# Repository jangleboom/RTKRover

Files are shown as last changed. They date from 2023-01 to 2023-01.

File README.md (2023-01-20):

# RTKRover
## Headtracker + Real Time Kinematics (RTK rover)

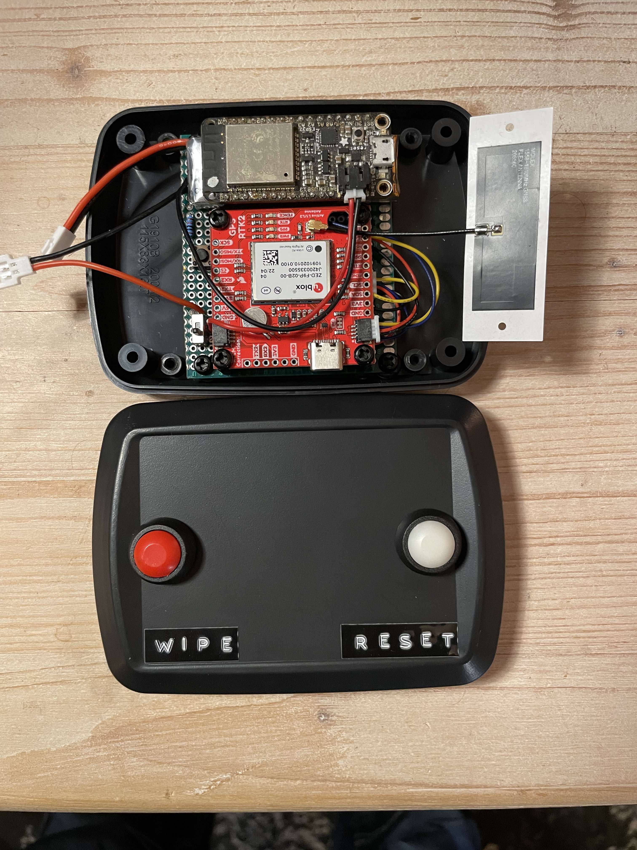
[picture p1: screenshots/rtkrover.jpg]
 

Hardware used:   
* Adafruit Feather ESP32 Huzzah 
* SparkFun GPS-RTK-SMA Breakout - ZED-F9P (Qwiic)
* SparkFun BNO080 Breakout
* ublox [ANN-MB1](https://www.u-blox.com/en/product/ann-mb-series?legacy=Current) antenna (the small one the picture is not used here at the moment)
* LiPo battery
* Push button(s)
* Resistor 10 k
* Switch

Infrastructure:
* WiFi (e. g. a personal hotspot)
* free line of sight between antenna (horizontal placed) an sky

### Dependencies
* [ESPAsyncWebServer](https://github.com/me-no-dev/ESPAsyncWebServer)
* [RTKRoverManager](https://github.com/jangleboom/RTKRoverManager)

### Circuit diagram
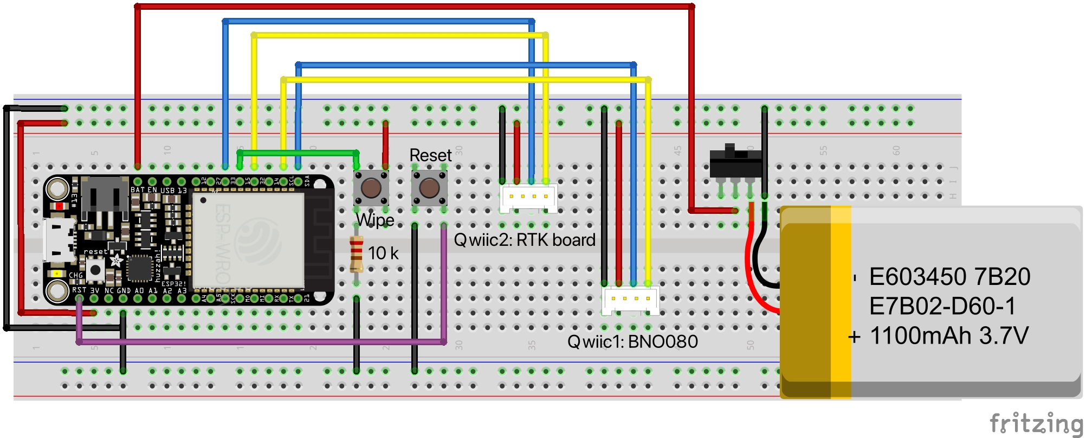
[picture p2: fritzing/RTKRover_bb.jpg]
plot


### Configuration

BNO080:

In main.cpp line 763 (or near) you can choose the way of sensor fusion in the BNO080.

````
  // Activate IMU functionalities
  // bno080.enableRotationVector(BNO080_ROT_VECT_UPDATE_RATE_MS);  
  // bno080.enableGameRotationVector(BNO080_ROT_VECT_UPDATE_RATE_MS);  
  bno080.enableARVRStabilizedRotationVector(BNO080_ROT_VECT_UPDATE_RATE_MS);

`````

more information in the [datasheet](https://www.ceva-dsp.com/wp-content/uploads/2019/10/BNO080_085-Datasheet.pdf)

ZED-F9P:

If you are NOT using the web form of the RTKBaseManager, then to connect to a caster you will need to fill out the CasterSecrets.h that lives in your src folder with your own credentials (and replace the vars with the k prefixed values e. g: ```mountPoint``` to ```kMountPoint``` in the main.cpp).

````
#ifndef CASTER_SECRETS_H
#define CASTER_SECRETS_H
// A place for your caster credentials

// RTK2Go http://www.rtk2go.com:2101/SNIP::STATUS#uptime

const char kCasterHost[] = "rtk2go.com"; 
const char kCasterPort[] = "2101";
const char kMountPoint[] = "YOUR_MOUNT_POINT";
const char kCasterUser[] = "YOUR_USER_EMAIL";           // User must provide their own email address to use RTK2Go
const char kCasterUserPw[] = "";                        // Not neccecary, more info: rtk2go.com

// Device name 
const char kDeviceName[] = "rover123";                  // E. g. 
// Wifi access
const char kWifiSsid[] = "YOUR_SSID_WITHOUT_SPACES";    // Wifi to connect the rover with
const char kWifiPw[] = "YOUR_WIFI_PASSWORD";

#endif /*** CASTER_SECRETS_H ***/

````

The mklittlefs file in the root dir you have to [get](https://github.com/earlephilhower/mklittlefs/releases) depending on your OS.
If you have the Arduino IDE installed, you can borrow it from there too. On macOS you can find it here: `~/Library/Arduino15/packages/esp32/tools/mklittlefs/3.0.0-gnu12-dc7f933/mklittlefs`.  Help for setup the file system you can find [here](https://randomnerdtutorials.com/esp8266-nodemcu-vs-code-platformio-littlefs/). This project was created on macOS (silicon).

[Support RTK2GO](http://new.rtk2go.com/donations-and-support/)

### ESP32 board LED error codes:

* 0.1 s BLE: not connected
* 0.5 s RTK: setupGNSS() failed (I2C setup)
* 1.0 s	RTK: setupGNSS() failed (I2C communication)
* 2.0 s RTK: credentialsExists false
* 1.0 s : 0.1 s WiFi: connection to AP lost

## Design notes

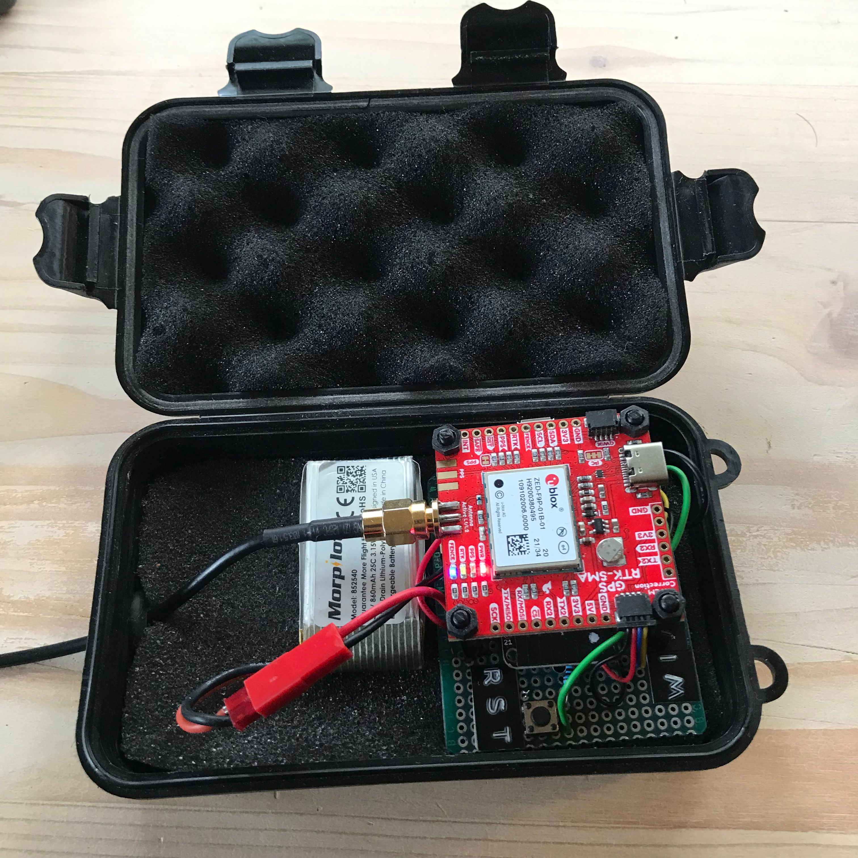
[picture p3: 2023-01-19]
screenshots/rtkrover.jpeg

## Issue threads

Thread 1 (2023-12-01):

Is the bno080 optional?

rcdemuth, 2023-12-01:
So, I'm trying to put together a rover.  I don't have one of the bno080 boards, and was wondering what it's role was.

jangleboom, 2023-12-12:
Hello rcdemuth, no – it is optional. However, if you don't want to use orientation tracking, you should comment out all of the associated BNO080 code. The device was built for an audio art project in acoustic virtual reality. In order to reproduce the sound dynamically depending on position and viewing direction, we needed both the BNO080 data and the GPS data. To use just the rover you don't need a BNO080.

Closed 2024-01-02.

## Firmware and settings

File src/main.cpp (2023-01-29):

/*******************************************************************************
 * @file main.cpp
 * @authors Markus Hädrich
 * <br>
 * @brief This is part of a distributed software, here: head tracker and GNSS 
 *        positioning using Sparkfun Real Time Kinematics
 * <br>
 * @todo  - Task to check / reconnect WiFi (independent of head tracking)
 *        - Calibration button (?)
 *        - Test: BNO080 found/connected
 *        - Test: BLE 
 *        - Status led for WiFi/BLE? on the device box or monitoring in app only?
 *        - Buzzer peep tone if lipo runs out of energy or show an blinky icon/notification in App
 *        
 * @note How to handle WiFi: 
 *        - Push the wipeButton, this will delete old entries in LittleFS files
 *        - Join the AP thats appearing 
 *            -# SSID: RTK-Rover now, later with more devices e. g. "RTKRover_" + ChipID 
 *            -# PW: e. g. "12345678"
 *        - Open address 192.168.4.1 in your browser and set credentials you are 
 *          using for you personal access point on your smartphone
 *        - If the process is done, the LED turns off and the device reboots
 *        - If there are no Wifi credentials stored in the LittleFS, the device 
 *          will jump in AP mode on startup
 * 
 *       How to measure battery:
 *        - First:  Since the ADC2 module is also used by the Wi-Fi, only one of 
 *                  them could get the preemption when using together, which means 
 *                  the adc2_get_raw() may get blocked until Wi-Fi stops, and 
 *                  vice versa. (https://docs.espressif.com/projects/esp-idf/en/latest/esp32/api-reference/peripherals/adc.html)
 *        - Second: Easiest way, use a fuel gauge breakout board e. g. Adafruit_LC709203F
 *                  Complicated way, implement an alternating usage of WiFi and ADC2
 * 
 * @version 0.43
 ******************************************************************************/


#include <Arduino.h>
#include <Wire.h> // BNO080 and uBlox GNSS
#include <BLEDevice.h>
#include <BLE2902.h>
#include <SparkFun_u-blox_GNSS_Arduino_Library.h>
#include <SparkFun_BNO080_Arduino_Library.h>
#include <utility/imumaths.h>
#include <sdkconfig.h>
#include <RTKRoverConfig.h>
#include <CasterSecrets.h>
#include <RTKRoverManager.h>
#include <TestsRTKRover.h>

using namespace RTKRoverManager;

/*
=================================================================================
                                Buttons
=================================================================================
*/
#include "Button2.h"

// Button to press to wipe out stored WiFi credentials
Button2 wipeButton = Button2(WIPE_BUTTON_PIN, INPUT, false, false);

void buttonHandler(Button2 &btn);

/*
=================================================================================
                                Battery
=================================================================================
*/
// Messure half the battery voltage
#define BAT_PIN                    A13
/**
 * @brief Get the Battery Volts 
 * 
 * @return float Battery voltage
 */
float getBatteryVolts(void);

/*
=================================================================================
                                WiFi
=================================================================================
*/
AsyncWebServer server(80);
String scannedSSIDs[MAX_SSIDS];

/*
=================================================================================
                                Bluetooth LE
=================================================================================
*/
float bleConnected = false; // TODO: deglobalize this

class MyCharacteristicCallbacks: public BLECharacteristicCallbacks 
{
    void onWrite(BLECharacteristic *pHeadtrackerCharacteristic) 
    {   
        std::string value = pHeadtrackerCharacteristic->getValue(); // Here I get the commands from the App (client)

        if (value.length() > 0) 
        {
            DBG.println(F("*********"));
            DBG.print(F("New value: "));
            for (int i = 0; i < value.length(); i++)
                DBG.print(value[i]);

            DBG.println();
            DBG.println(F("*********"));
        }
     }

     void onConnect(BLEServer* pServer) 
     {
        bleConnected = true;
        DBG.print(F("bleConnected: "));
        DBG.println(bleConnected);
     };

    void onDisconnect(BLEServer* pServer) 
    {
        bleConnected = false;
        DBG.print(("bleConnected: "));
        DBG.println(bleConnected);
    }
};

class MyServerCallbacks: public BLEServerCallbacks 
{
    void onConnect(BLEServer* pServer) 
    {
        bleConnected = true;
        BLEDevice::stopAdvertising();
    };

    void onDisconnect(BLEServer* pServer) 
    {
        bleConnected = false;
        BLEDevice::startAdvertising();
    }
};

BLECharacteristic *pHeadtrackerCharacteristic;
BLECharacteristic *pRealtimeKinematicsCharacteristic;
BLECharacteristic *pRTKAccuracyCharacteristic;

void setupBLE(void);
/*
=================================================================================
                                BNO080
=================================================================================
*/
BNO080 bno080;
void setupBNO080(void);

/*
=================================================================================
                                GNSS
=================================================================================
*/
long lastTime = 0; //Simple local timer. Limits amount if I2C traffic to Ublox module.
bool beginPositioning = false;  // Wait with positioning for first correction data from caster

// The ESP32 core has a built in base64 library but not every platform does
// We'll use an external lib if necessary.
#if defined(ARDUINO_ARCH_ESP32)
#include "base64.h" //Built-in ESP32 library
#else
#include <Base64.h> //nfriendly library from https://github.com/adamvr/arduino-base64, will work with any platform
#endif


SFE_UBLOX_GNSS myGNSS;

/**
 * @brief Setup the ZED-F9D to a rover
 * 
 * @return true If succeeded
 * @return false If failed
 */
bool setupGNSS(void);

/**
 * @brief Start the
 * 
 */
void beginClient(void);

/**
 * @brief Get the Position
 * 
 */
void updatePosition(void);

/*
=================================================================================
                                FreeRTOS
=================================================================================
*/
typedef struct Coord
{
  int32_t lat;
  int8_t  latHp;
  int32_t lon;
  int8_t  lonHp;
} coord_t;

const uint8_t QUEUE_SIZE = 2;
xQueueHandle xQueueAccuracy, xQueueCoord;
static xSemaphoreHandle mutexSem;

/**
 * @brief Task to get the correction data from the caster server
 *        using WiFi
 * 
 * @param pvParameters Void pointer, no parameter used here
 */
void task_rtk_get_corrrection_data(void *pvParameters);

/**
 * @brief Task to get location data
 * 
 * @param pvParameters 
 */

void task_rtk_get_rover_position(void *pvParameters);
/**
 * @brief Task for sending the corrected location data to the
 *        iPhone using BLE
 * 
 * @param pvParameters Void pointer, no parameter used here
 */
void task_send_rtk_position_via_ble(void *pvParameters);

/**
 * @brief Task for sending the BNO080 position data to the
 *        iPhone using BLE
 * 
 * @param pvParameters Void pointer, no parameter used here
 */
void task_bno_orientation_via_ble(void *pvParameters);

/**
 * @brief Create the queues with the right size
 * 
 */
void xQueueSetup(void);

/**
 * @brief Function that blinks one time
 * 
 * @param blinkTime       Blink time in ms
 * @param doNotBlock  Kind of delay between blinking
 */
void blinkOneTime(int blinkTime, bool doNotBlock);

/**
 * @brief Deletes WiFi station SSID and PW from LittleFS
 * 
 */
void wipeWiFiCredentials(void);

void setup() 
{
  // Board LED used for error codes (written in README.md)
  pinMode(LED_BUILTIN, OUTPUT);
  digitalWrite(LED_BUILTIN, LOW);

  #ifdef DEBUGGING
  Serial.begin(BAUD);
  while (!Serial) {};
  #endif

 //===============================================================================
  // Initialize LittleFS
  // Use board_build.partitions in platformio.ini
  if (!setupLittleFS()) 
  {
    formatLittleFS();
    if (!setupLittleFS()) while (true) {};
  }

  // The following function clear the file system and that will cause a setup as AP to enter new data

  // Uncomment if you want to format (e. g after changing partition sizes)
  // (And dont forget to comment this again after one run ;)
  //formatLittleFS();

  // wipeWiFiCredentials();  // Use this for deleting WiFi data only
  // wipeLittleFSFiles();  // Use this for deleting all data
#ifdef DEBUGGING
  listFiles();
  delay(3000);
#endif

  //===============================================================================
  // Wifi setup AP or STATION, depending on data in LittleFS
  setupWiFi(&server);
  delay(1000);

  while (WiFi.getMode() == WIFI_AP) 
  {
    DBG.println(F("Enter Wifi credentials on webform:"));
    DBG.print(F("Connect your computer to SSID: "));
    DBG.println(WiFi.getHostname());
    DBG.print(F("Go with your Browser to IP: "));
    DBG.println(WiFi.softAPIP());
    blinkOneTime(1000, false);
    blinkOneTime(100, false);
  }
  if (WiFi.getMode() == WIFI_STA) 
  {
    while (! WiFi.isConnected())
    {
      DBG.println(F("setup(): Try reconnect to WiFi station"));
      WiFi.reconnect();
      DBG.printf("WiFi state: %s", WiFi.isConnected() ? "connected" : "disconnected");
      blinkOneTime(1000, false);
      blinkOneTime(100, false);
    }
  }
//===============================================================================
  
  setupBLE();
  
  DBG.print(F("Device type: ")); DBG.println(DEVICE_TYPE);
  DBG.print(F("Battery: "));
  DBG.print(getBatteryVolts());  
  DBG.println(" V");

  wipeButton.setPressedHandler(buttonHandler); // Pull down method is done in wipeButton init

  // FreeRTOS
  mutexSem = xSemaphoreCreateMutex();
  xQueueSetup();
/*  
  Stack sizes of the tasks. You have to measure the used size in the task (set a high value for first run) and 
  after that you can reduce the stack size to an fitting smaller value. This have to repeated if 
  the task code is changed. There are no rules, just measure and adjust (thats why its a magic number).
  For measurement you need to uncomment the uxHighWaterMark related code in the task (setup and loop).
  After measurement comment out it again.
*/
  int stack_size_task_rtk_get_corrrection_data = 1024 * 7;          // Last measurement: 
  int stack_size_task_rtk_get_rover_position = 1024 * 7;      // Last measurement: 5844 
  int stack_size_task_bno_orientation_via_ble = 1024 * 11;  // Last measurement:
  int stack_size_task_send_rtk_position_via_ble = 1024 * 10;     // Last measurement: 9480
  
  xTaskCreatePinnedToCore( &task_rtk_get_corrrection_data, "task_rtk_get_corrrection_data", stack_size_task_rtk_get_corrrection_data, NULL, TASK_RTK_GET_CORR_DATA_PRIORITY, NULL, RUNNING_CORE_0);
  xTaskCreatePinnedToCore( &task_rtk_get_rover_position, "task_rtk_get_rover_position", stack_size_task_rtk_get_rover_position, NULL, TASK_RTK_GET_POSITION_PRIORITY, NULL, RUNNING_CORE_0);
  xTaskCreatePinnedToCore( &task_bno_orientation_via_ble, "task_bno_orientation_via_ble", stack_size_task_bno_orientation_via_ble, NULL, TASK_BNO080_VIA_BLE_PRIORITY, NULL, RUNNING_CORE_1);
  xTaskCreatePinnedToCore( &task_send_rtk_position_via_ble, "task_send_rtk_position_via_ble", stack_size_task_send_rtk_position_via_ble, NULL, TASK_RTK_POSITION_VIA_BLE_PRIORITY, NULL, RUNNING_CORE_1);
  
  String thisBoard = ARDUINO_BOARD;
  DBG.print(F("Setup done on "));
  DBG.println(thisBoard);
}

void loop() 
{
  #ifdef DEBUGGING
  aunit::TestRunner::run();
  #endif

  wipeButton.loop();
}

/*
=================================================================================
                                GNSS
=======================================_==========================================
*/
bool setupGNSS() 
{
    while (!Wire1.begin(RTK_SDA_PIN, RTK_SCL_PIN)) 
    {
      DBG.println(F("I2C for RTK not running, check cable!"));
      delay(500);
    }

    Wire1.setClock(I2C_FREQUENCY_400K);

    while (myGNSS.begin(Wire1, RTK_I2C_ADDR) == false)
    {
      DBG.println(F("u-blox GNSS not detected at default I2C address. Please check wiring. Freezing loop."));
      blinkOneTime(500, false);
    }

    bool response = true;
    //Turn off NMEA noise
    response &= myGNSS.setI2COutput(COM_TYPE_UBX); 
    //Be sure RTCM3 input is enabled. UBX + RTCM3 is not a valid state.
    response &= myGNSS.setPortInput(COM_PORT_I2C, COM_TYPE_UBX | COM_TYPE_NMEA | COM_TYPE_RTCM3); 
    response &= myGNSS.setHighPrecisionMode(true);
    // Set output in Hz.
    response &= myGNSS.setNavigationFrequency(NAVIGATION_FREQUENCY_HZ); 
    byte rate = myGNSS.getNavigationFrequency(); //Get the update rate of this module
    DBG.print("Current update rate: ");
    DBG.println(rate);

    return response;
}

void updatePosition() 
{
  static int32_t old_accuracy = -1;
  coord_t coord;

  myGNSS.checkUblox();

  int32_t lat = myGNSS.getHighResLatitude();
  int8_t latHp = myGNSS.getHighResLatitudeHp();
  int32_t lon = myGNSS.getHighResLongitude();
  int8_t lonHp = myGNSS.getHighResLongitudeHp();
  int32_t accuracy = myGNSS.getPositionAccuracy();

  coord = {.lat = lat, .latHp = latHp, .lon = lon, .lonHp = lonHp};
  xQueueSend(xQueueCoord, &coord, portMAX_DELAY); 

  // Send accuracy if changed only
  if (accuracy != old_accuracy)
  {
    xQueueSend( xQueueAccuracy, &accuracy, portMAX_DELAY );
    old_accuracy = accuracy;
  }

}

/*
=================================================================================
                                FreeRTOS
=================================================================================
*/

void task_rtk_get_rover_position(void *pvParameters) 
{
  (void)pvParameters;

  // Measure stack size
  UBaseType_t uxHighWaterMark; 

  // Wait for first correction data
  while ( ! beginPositioning) { vTaskDelay(1000/portTICK_PERIOD_MS); }

  while (true)
  {
    if (xSemaphoreTake(mutexSem, portMAX_DELAY))
    {
      updatePosition();

      // Measure stack size (last was 2304)
      // uxHighWaterMark = uxTaskGetStackHighWaterMark( NULL );
      // DBG.print(F("task_rtk_get_rover_position loop, uxHighWaterMark: "));
      // DBG.println(uxHighWaterMark);

      xSemaphoreGive(mutexSem);
    }
   
    vTaskDelay(TASK_RTK_GET_POSITION_INTERVAL_MS/portTICK_PERIOD_MS);
  }
  vTaskDelete(NULL);
}

void task_rtk_get_corrrection_data(void *pvParameters) 
{
  (void)pvParameters;

  if (!setupGNSS()) 
  { 
    DBG.println("setupGNSS() failed! Restart in 10 s");
    while (true) 
    {
      static const int timeToReboot = 10000;
      static int counter = 0;
      blinkOneTime(1000, true);
      counter++;
      if (counter > 5) ESP.restart();
    }
  };

  while ( ! checkConnectionToWifiStation() )
  {
    DBG.println(F("task setup: Not connected to WiFi station"));
    blinkOneTime(1000, true);
    blinkOneTime(100, true);
  }
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

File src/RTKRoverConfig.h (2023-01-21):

#ifndef RTK_ROVER_CONFIG_H
#define RTK_ROVER_CONFIG_H
#include <Arduino.h>

// Deactivate brown out detection
#undef ESP_ERROR_CHECK
#define ESP_ERROR_CHECK(x)   do { esp_err_t rc = (x); if (rc != ESP_OK) { ESP_LOGE("err", "esp_err_t = %d", rc); assert(0 && #x);} } while(0);

/*
=================================================================================
                                Serial settings
=================================================================================
*/

// Set to true for debug mode, false for production mode
#define DEBUGGING true 
#define DBG \
  if (DEBUGGING) Serial

#ifdef DEBUGGING
#define TESTING
#endif

#define BAUD                          115200

/*
=================================================================================
                                WiFi settings
=================================================================================
*/
#define DEVICE_TYPE                  "rtkrover"
#define DEFAULT_KEY                  "12345678"

/*
=================================================================================
                                RTK settings
=================================================================================
*/
#define RTK_I2C_ADDR                0x42
#define RTK_SDA_PIN                 33
#define RTK_SCL_PIN                 32

/*
=================================================================================
                                BLE settings
=================================================================================
*/
#define PAYLOAD_BUF_LEN              20
#define SERVICE_UUID                            "713D0000-503E-4C75-BA94-3148F18D941E"
#define HEADTRACKER_CHARACTERISTIC_UUID         "713D0002-503E-4C75-BA94-3148F18D941E"
#define REALTIME_KINEMATICS_CHARACTERISTIC_UUID "713D0004-503E-4C75-BA94-3148F18D941E"
#define RTK_ACCURACY_CHARACTERISTIC_UUID        "713D0006-503E-4C75-BA94-3148F18D941E"
#define LIN_ACCEL_Z_DECIMAL_DIGITS   2
#define DATA_STR_DELIMITER           " "

/*
=================================================================================
                                BNO080 settings
=================================================================================
*/
/*  
INFO: The Qwiic VR IMU has onboard I2C pull up resistors; if multiple sensors are 
connected to the bus with the pull-up resistors enabled, the parallel 
equivalent resistance will create too strong of a pull-up for the bus to 
operate correctly. As a general rule of thumb, disable all but one pair of 
pull-up resistors if multiple devices are connected to the bus. If you need to 
disconnect the pull up resistors they can be removed by removing the solder on 
the corresponding jumpers labeled with "I2C" on the board.

BUT: we use here two I2C connections for real parallel computing on two cores.
*/
#define BNO080_I2C_ADDR                 0x4B
#define BNO080_SDA_PIN                  23
#define BNO080_SCL_PIN                  22
#define I2C_FREQUENCY_100K              100000  // 100 kHz
#define I2C_FREQUENCY_400K              400000  // 400 kHz
#define BNO080_ROT_VECT_UPDATE_RATE_MS  10      // Time between sensor readings
#define BNO080_LIN_ACCEL_UPDATE_RATE_MS 10      // 100 Hz
#define BNO080_STEP_CNT_UPDATE_RATE_MS  32      // 31.25 Hz lt. datasheet
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

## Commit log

2023-01-21 Board LED used for error codes, setup first
    [main.cpp]
2023-01-21 Error blink code added
    [main.cpp]
2023-01-24 LED error codes corrected
    [main.cpp]
2023-01-29 ESP.restart() added for case if setupGNSS failes
    [main.cpp]
2023-01-29 Reconnect Wifi loop must block in task, otherwise device is too busy too succeed
